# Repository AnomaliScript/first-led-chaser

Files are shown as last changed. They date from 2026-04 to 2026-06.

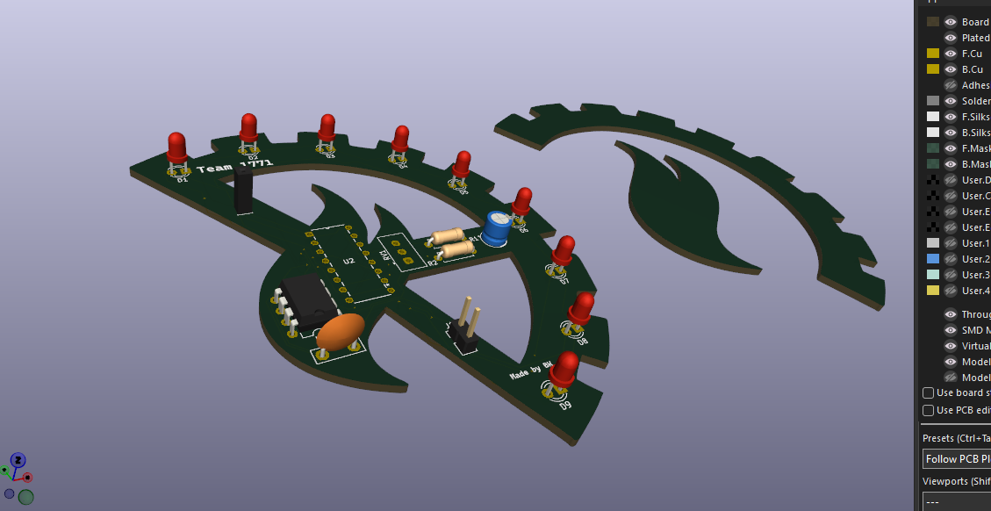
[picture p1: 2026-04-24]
Screenshot 2026-04-22 232021.png

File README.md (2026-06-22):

# first-led-chaser
This project is meant to be an introduction to KiCad, as I have never fully, independently made a schematic before :(  Let's hope I can make this successfully!

## How to Use It
An LED Chaser is basically those glowing, flashy arcade signs that have a series of LEDs (not necessarily a series circuit, mind you) that light up in a particular order, whether it be every other LED that switches or the blinking LED follows a circular pattern.
It's purely for flashiness and style, and it looks cool!  For a project like mine, it can even show team spirit.  (Read more too see what team I'm making this LED Chaser for).

## Story and Why I Made This
First step of making the PCB is making the schematics.  In order to create a schematic, I used KiCad's schematic tool, and I placed a couple of components down, until I realized I needed to pull some components and their footprints (a footprint is what represents the component in the PCB editor) from a database called "Ultra Librarian" by Texas Instruments (they sponsor quite a lot of robotics teams).  After getting the needed schematics, I wired them together with the green copper lines, and learned how to use labels and global labels (global labels are the labels in the arrow shapes).


When switching over to the PCB editor for the second part of my project, I had to assign footprints to every one of the schematics: this is where Ultra Librarian helped me out in finding some footprints thatthe KiCad default library doesn't naturally have.


after hunting down all the footprints, I made the PCB board's shape.  This LED chaser I made is in the shape of my FRC Robotics Team's (1771) logo, and wiring it all together with the front and back coppers, with the help of vias, wasn't too daunting of a task the more I connected components.
It kinda felt like a game, connecting all of them together :)


Anyways, here's the final 3D result!


I'm debating on whether to make a case for it: I decided against it.

## BOM (my version)
0.01 uF Capacitors: [link](https://www.amazon.com/Cermant-Ceramic-Capacitor-Electronic-Components/dp/B09XV2CZJZ/ref=sr_1_3?sr=8-3)
1 uF Capacitors (and many more capacitors): [link](https://www.amazon.com/200PCS-Electrolytic-Capacitor-Kit-Electronics/dp/B0FH1R7N94/ref=sr_1_4?sr=8-4)
Connectors: [link](https://www.amazon.com/Glarks-Connector-Assortment-Stackable-Breakaway/dp/B07CWSXY7P)
4017BE: [link](https://www.amazon.com/Texas-Instruments-CD4017BE-Counter-Decoded/dp/B00GAGD10Y)
NE555N Clock: [link](https://www.amazon.com/ALLECIN-NE555-NE555P-Timer-NE555N/dp/B0CBKFMWDP)
T93YA: [link](https://www.digikey.com/en/products/detail/vishay-sfernice/T93YA103KT20/1587711)
In total, this project cost me about **$30** to make (yikes...)

## End Result
Fortunately, I got help from a friend when his dad agreed to lend me his solder and soldering iron.
When I initially soldered the PCB, [the blinking was really fast](https://drive.google.com/file/d/1CZGWTpNvm0oBers0KX6bNRDRQLqv2583/view?usp=sharing), even when I set the potentiometer to its "highest resistance" mode, which is stupposed to slow down the blinking rate.
After asking AI for help, I decided to replace the capacitor (which was originally 1uF) with a 10uF capacitor.

This solution worked, and after a few close burns, and the blinker works: a video of it blinking can be found [here](https://drive.google.com/file/d/13T7uWkx8QOqEzrhQr9J85-se3VObvKnz/view?usp=sharing) (the capacitor laying near the PCB was the 1uF capacitor that I removed).
Despite the blinker being a bit finicky at times, I learned a lot from this experience, and I'm still proud of the result.


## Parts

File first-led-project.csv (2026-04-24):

Id | Designator | Footprint | Quantity | Designation | Supplier and ref
1 | C3 | CP_Radial_D5.0mm_P2.00mm | 1 | 1 uF
2 | C4 | C_Disc_D7.5mm_W2.5mm_P5.00mm | 1 | 0.01 uF
3 | D1, D2, D3, D4, D5, D6, D7, D8, D9 | LED_D3.0mm | 9 | LED
4 | J1 | PinHeader_1x02_P2.54mm_Vertical | 1 | Conn_01x02_Socket
5 | J2 | PinSocket_1x01_P2.54mm_Vertical | 1 | Conn_01x01_Socket
6 | R1 | R_Axial_DIN0207_L6.3mm_D2.5mm_P7.62mm_Horizontal | 1 | 470
7 | R2 | R_Axial_DIN0207_L6.3mm_D2.5mm_P7.62mm_Horizontal | 1 | 1k
8 | RV1 | Potentiometer_Vishay_T93YA_Vertical | 1 | 50k
9 | U1 | DIP-8_W7.62mm | 1 | NE555P
10 | U2 | N16 | 1 | 4017

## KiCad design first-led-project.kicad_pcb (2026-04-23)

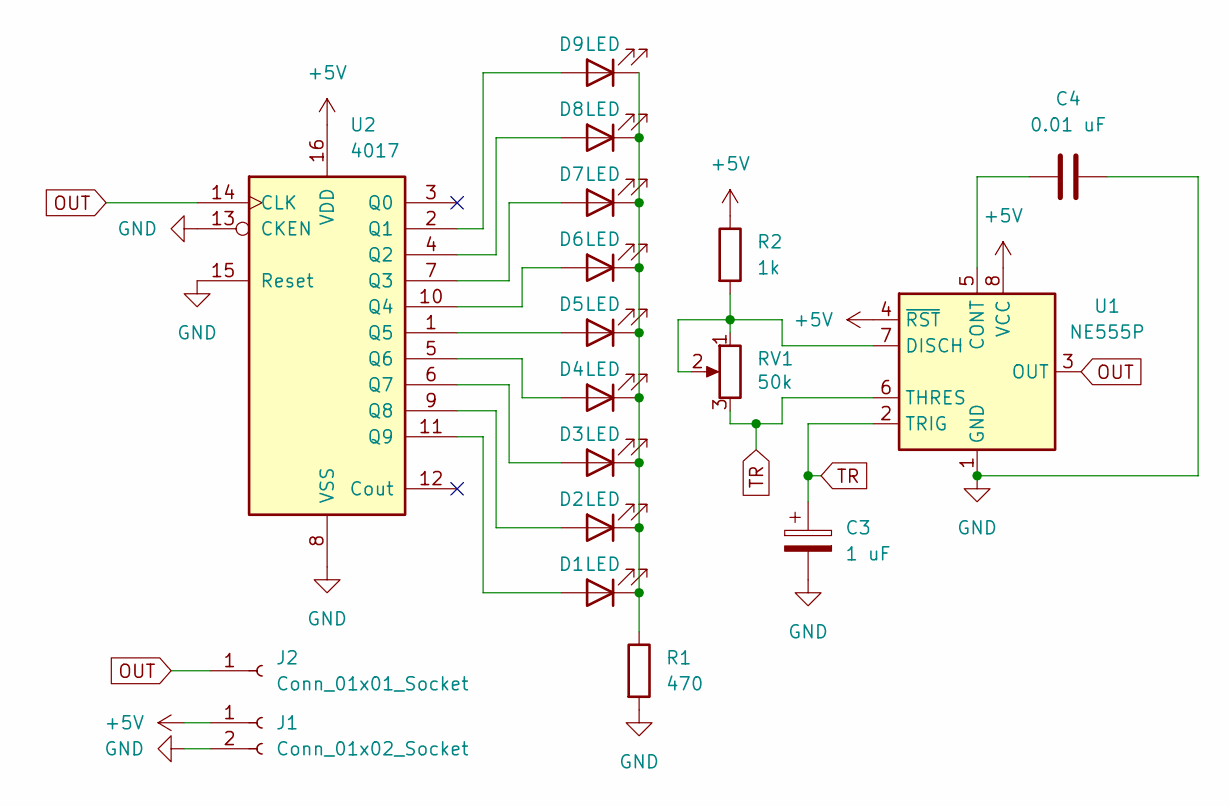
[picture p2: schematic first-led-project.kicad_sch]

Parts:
C3: 1 uF; CP_Radial_D5.0mm_P2.00mm
C4: 0.01 uF; C_Disc_D7.5mm_W2.5mm_P5.00mm
D1, D2, D3, D4, D5, D6, D7, D8, D9: LED; LED_D3.0mm
J1: Conn_01x02_Socket; PinHeader_1x02_P2.54mm_Vertical
J2: Conn_01x01_Socket; PinSocket_1x01_P2.54mm_Vertical
R1: 470; R_Axial_DIN0207_L6.3mm_D2.5mm_P7.62mm_Horizontal
R2: 1k; R_Axial_DIN0207_L6.3mm_D2.5mm_P7.62mm_Horizontal
RV1: 50k; Potentiometer_Vishay_T93YA_Vertical
U1: NE555P; DIP-8_W7.62mm
U2: 4017; N16

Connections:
+5V: J1.1, R2.1, U1.4 (~RST), U1.8 (VCC), U2.16 (VDD)
GND: C3.2, C4.2, J1.2, R1.2, U1.1 (GND), U2.8 (VSS), U2.13 (CKEN), U2.15 (Reset)
unnamed: D1.2 (A), U2.11 (Q9)
unnamed: D1.1 (K), D2.1 (K), D3.1 (K), D4.1 (K), D5.1 (K), D6.1 (K), D7.1 (K), D8.1 (K), D9.1 (K), R1.1
unnamed: D2.2 (A), U2.9 (Q8)
unnamed: D3.2 (A), U2.6 (Q7)
unnamed: D4.2 (A), U2.5 (Q6)
unnamed: D5.2 (A), U2.1 (Q5)
unnamed: D6.2 (A), U2.10 (Q4)
unnamed: D7.2 (A), U2.7 (Q3)
unnamed: D8.2 (A), U2.4 (Q2)
unnamed: D9.2 (A), U2.2 (Q1)
unnamed: C4.1, U1.5 (CONT)
unnamed: R2.2, RV1.1, RV1.2, U1.7 (DISCH)
OUT: J2.1 (Pin_1_1), U1.3 (OUT), U2.14 (CLK)
TR: C3.1, RV1.3, U1.2 (TRIG), U1.6 (THRES)

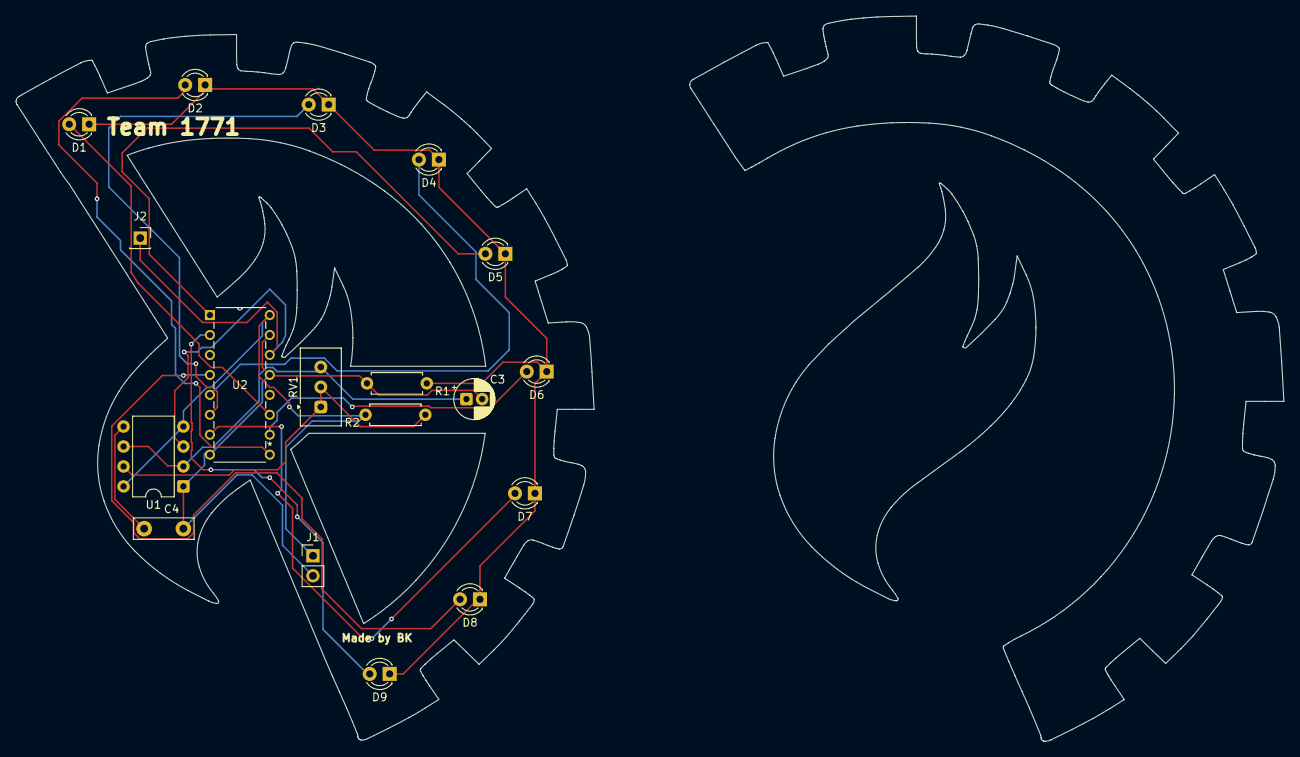
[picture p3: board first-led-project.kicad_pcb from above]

Board: 2 copper layers, 73.6 x 89.8 mm, 18 parts (0 on the bottom side), 16 nets.

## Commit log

2026-04-24 Adding Gerbers
2026-04-24 Adding BOM
    [first-led-project.csv]
2026-04-24 Update README with project details and usage
    Added sections on usage, story, and end result of the LED Chaser project.
2026-05-21 Revise case decision and add BOM section
    Updated the decision on making a case and added a BOM section with links to components.
2026-06-22 Update README with project cost and soldering details
    Added project cost and detailed soldering experience.
